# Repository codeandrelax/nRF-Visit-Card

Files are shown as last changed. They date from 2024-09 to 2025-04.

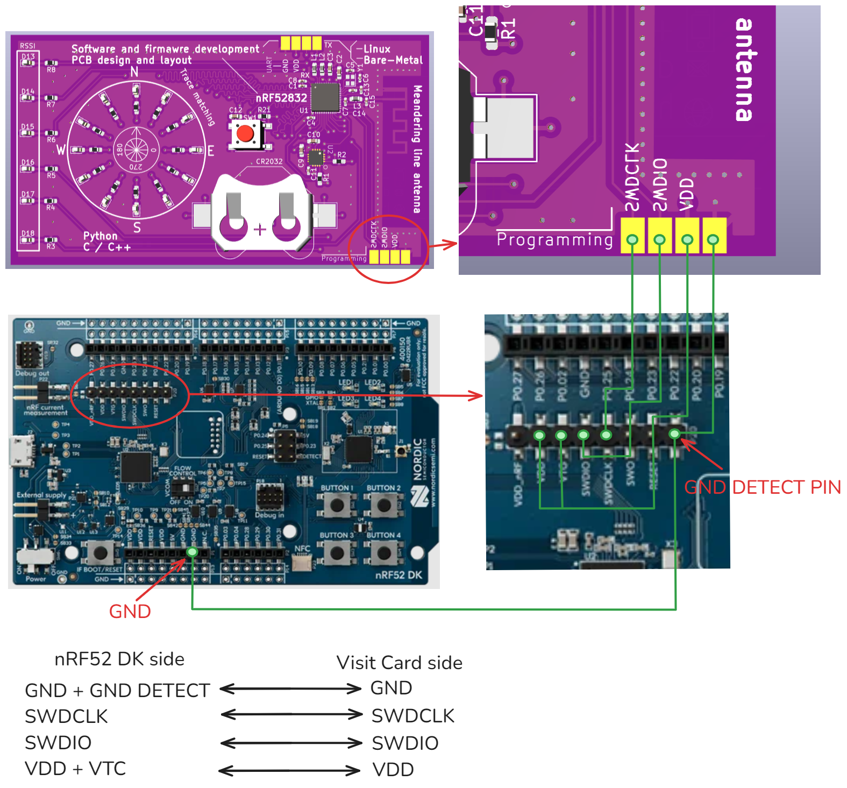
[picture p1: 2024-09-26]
visitCard_programming_witg_nRF52_DK.png

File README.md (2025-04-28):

# Bluetooth Compass Project

This project is a personal showcase of my skills in **PCB design, embedded firmware development, and Android application programming**—centered around a custom-built **Bluetooth-enabled digital compass**.

I created this project as a demonstration of my capability to design and manufacture a clean, self-contained PCB solution, free from the reliance on off-the-shelf BLE modules. It’s a manifestation of my passion for building systems from scratch, with a focus on RF design and embedded software.

---

## 🛠️ Hardware Overview

- **Microcontroller**: Nordic nRF52832 with integrated BLE support  
- **Antenna**: Custom-designed **meandering line antenna** tuned to **2.4 GHz**  
- **Magnetometer**: QMC5883L for 3-axis magnetic field sensing (I2C communication)  
- **LEDs**:  
  - 12x Blue LEDs in a circular layout to represent compass directions  
  - 6x Status LEDs: USER, CONNECTIVITY INDICATOR, HEARTBEAT  
- **Battery**: CR2032 coin cell slot  
- **Programming Interface**: SWD (SWCLK, SWDIO), UART connector  
- **Clock**: 32 MHz external crystal for BLE SoftDevice  
- **PCB Stack**: 4-layer custom design, credit-card sized  

> The reset pin is repurposed as a **user input button**. The reset functionality is disabled in software to allow this.

---

## 🔧 Firmware Overview

Firmware is built on **Zephyr RTOS**, enabling modular and modern embedded software design.

A **custom Bluetooth service**, `CompassService`, is implemented, exposing three key characteristics:

1. **Button State**  
2. **User LED Control**  
3. **Direction Output**

### 📡 Magnetometer Integration

- QMC5883L communicates over I2C.  
- Each axis (X, Y, Z) is read as a signed 16-bit value:

```c
int16_t value = (MSB << 8) | LSB;
```

- Orientation is calculated using the X and Y components:

```c
float angle_rad = atan2f((float)mag_y, (float)mag_x);
float angle_deg = angle_rad * (180.0f / M_PI);
if (angle_deg < 0) angle_deg += 360.0f;
```

The direction value is then:
- **Broadcast over BLE** using notify characteristics  
- **Rendered via LEDs** in a circular fashion to act as a real-time compass  

The system runs on the **internal RC oscillator**, while the **external crystal is reserved for BLE operations**.

---

## 📱 Android App Overview

Developed using **Android Studio**, the app uses the **Processing library** to render a dynamic compass needle.

- **BLE scanning** locates the `BluetoothCompass`  
- On connection, the app:  
  - Performs **service discovery**  
  - **Subscribes** to the `Direction` characteristic  
  - **Updates** the compass needle UI in real-time  

This part was relatively straightforward and served as a creative outlet for UI/UX.

---

## 🎯 Purpose

This project was built as a **self-test and demonstration** of:

- Designing an RF-friendly PCB with custom Bluetooth antenna  
- Working with the **nRF52 ecosystem** and BLE stack (SoftDevice + Zephyr)  
- Integrating hardware components like magnetometers and CR2032 power  
- Creating a polished **user-facing Android application**

---

## 🧠 Lessons Learned

Building this project wasn't without hiccups—but every mistake taught me something valuable:

1. **Reversed Magnetometer Pins**  
   Costly PCB error discovered only post-manufacturing. Lesson: Triple-check schematic-to-layout connections.

2. **QFN Soldering Difficulties**  
   My aging soldering iron made soldering QFN packages (magnetometer, MCU) unreliable. Eventually outsourced to **JLCPCB assembly** for these parts.

3. **Signed-to-Unsigned Mistake**  
   I accidentally cast signed 16-bit values from the magnetometer to `uint16_t`, causing direction errors—reminding me of the infamous Ariane 5 bug.

4. **Magnetometer Proximity to Battery**  
   The CR2032 placement near the magnetometer introduced magnetic interference. If I were to redo the board, I’d increase their separation.

5. **No Tilt Compensation**  
   Since the magnetometer acts as a compass only when the board is level, tilts skew the readings. A better design would include an **accelerometer** for tilt compensation:

   ```
   heading = atan2(-Y, X)
   pitch = asin(Z / sqrt(X² + Y² + Z²))
   compensated_heading = heading adjusted for pitch/roll
   ```

---

## 🏁 Conclusion

This project embodies my passion for **electronics**, **firmware engineering**, and **RF system design**. Despite having a **Master’s degree in electronics** and professional experience in embedded development, this personal build was a humbling and rewarding journey. Interestingly, the Android app—which I only work on as a hobby—turned out to be the smoothest part of the whole process!

---

## 🤝 Feedback Welcome!

I enjoy building things I can be proud of—and I’m always open to feedback and suggestions.  
If anything in this project sparks your interest or you’d like to collaborate, feel free to reach out.

## Detailed



This is how it started:



### Schematics























### Layout - bottom copper layer



### Rendered images of the board



### Soldered board



# nRF Connect notes

## How to program the board

[nRF52 DK](https://www.nordicsemi.com/Products/Development-hardware/nRF52-DK) can be used to program the visit card. 

nRF Visit Card board has exposed pads that are used for programming.
visitCard_programming_witg_nRF52_DK

### Pinout



## Internal oscilator enable

To enable internal oscilator for nRF52832 in the proj.conf file add:
````
CONFIG_CLOCK_CONTROL_NRF_K32SRC_RC=y
CONFIG_CLOCK_CONTROL_NRF_K32SRC_500PPM=y
CONFIG_CLOCK_CONTROL_NRF_K32SRC_RC_CALIBRATION=y
CONFIG_CLOCK_CONTROL_NRF_CALIBRATION_LF_ALWAYS_ON=y
````

## Enable rest pin to be input GPIO

In the overlay file add:

```
&uicr {
	/delete-property/ gpio-as-nreset;
};
```

after it make sure to call:

```
nrfjprog --eraseuicr
nrfjprog --program <path to hex file> --verify
```

 You might need to reset the board after this - unplug it and plug it back in.

## If _printk_ is not working
In the proj.conf file add:
````
CONFIG_CONSOLE=y
````
## Disabling NFC pins
Pins P0.09 and P0.10 are NFC pins and if you wan't to use them as GPIO pins you need to disable NFC.
[nrf52 enabling gpio on nfc pins](https://devzone.nordicsemi.com/f/nordic-q-a/35505/nrf52-enabling-gpio-on-nfc-pins)
```
CONFIG_NFCT_PINS_AS_GPIOS=y
```

## Enable printing via SWD IO and SWD CLK
In the proj.conf file add:
```
CONFIG_LOG=y
CONFIG_UART_CONSOLE=n
CONFIG_RTT_CONSOLE=y
CONFIG_USE_SEGGER_RTT=y
```
then you can use `printf` function.
```
uint16_t a = getAzimuth();
printf("Azimuth: %d\n", a);
```
Make sure to connect to RTT (Real-Time Transfer).



## 

 # Knowledge Library

 [nRF Connect SDK Fundamentals](https://academy.nordicsemi.com/courses/nrf-connect-sdk-fundamentals/)
 
 [Bluetooth Low Energy Fundamentals](https://academy.nordicsemi.com/courses/bluetooth-low-energy-fundamentals/)

 [Find BLE devices](https://developer.android.com/develop/connectivity/bluetooth/ble/find-ble-devices#java)

 [Processing for Android](https://android.processing.org/tutorials/android_studio/index.html)

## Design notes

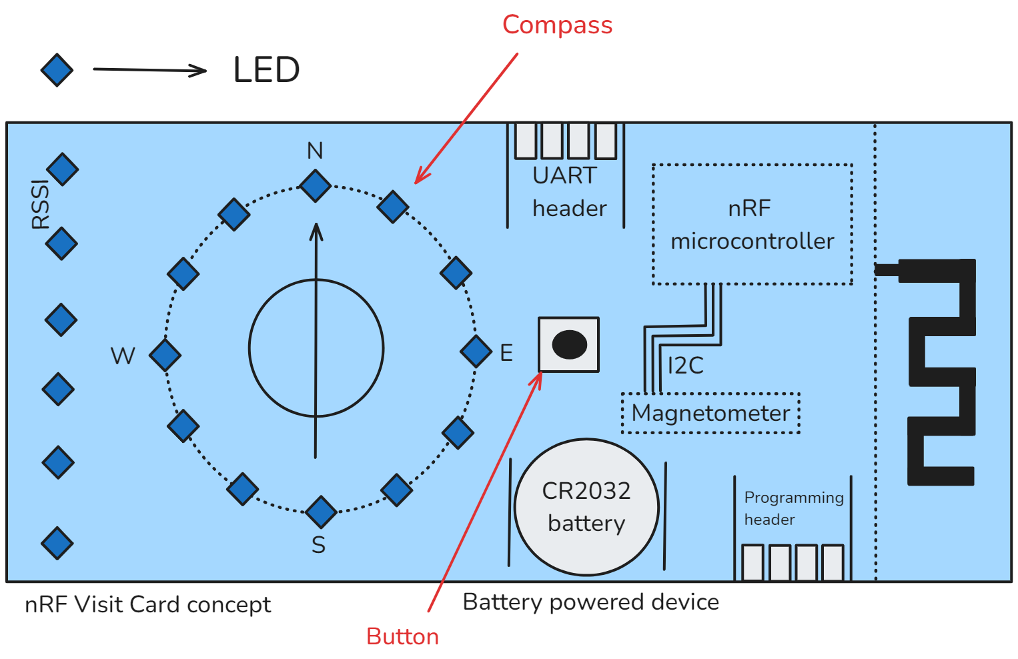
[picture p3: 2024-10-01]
nRF_visitcard_concept.png

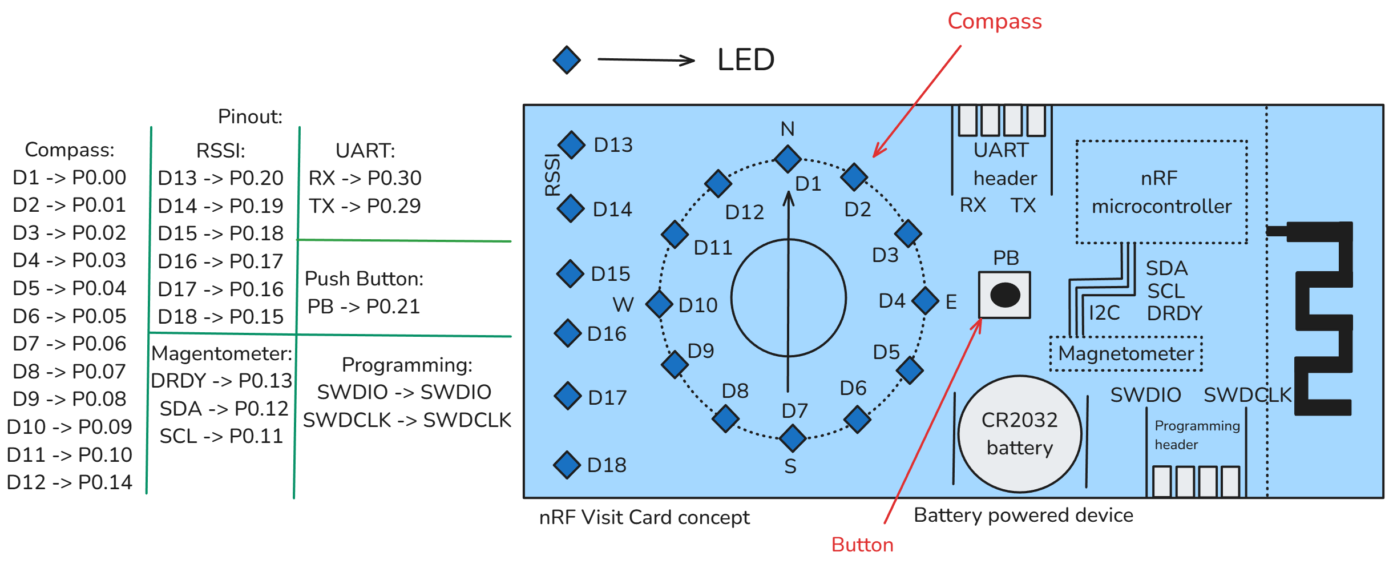
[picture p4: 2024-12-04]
nRF_visitcard_pinout.png

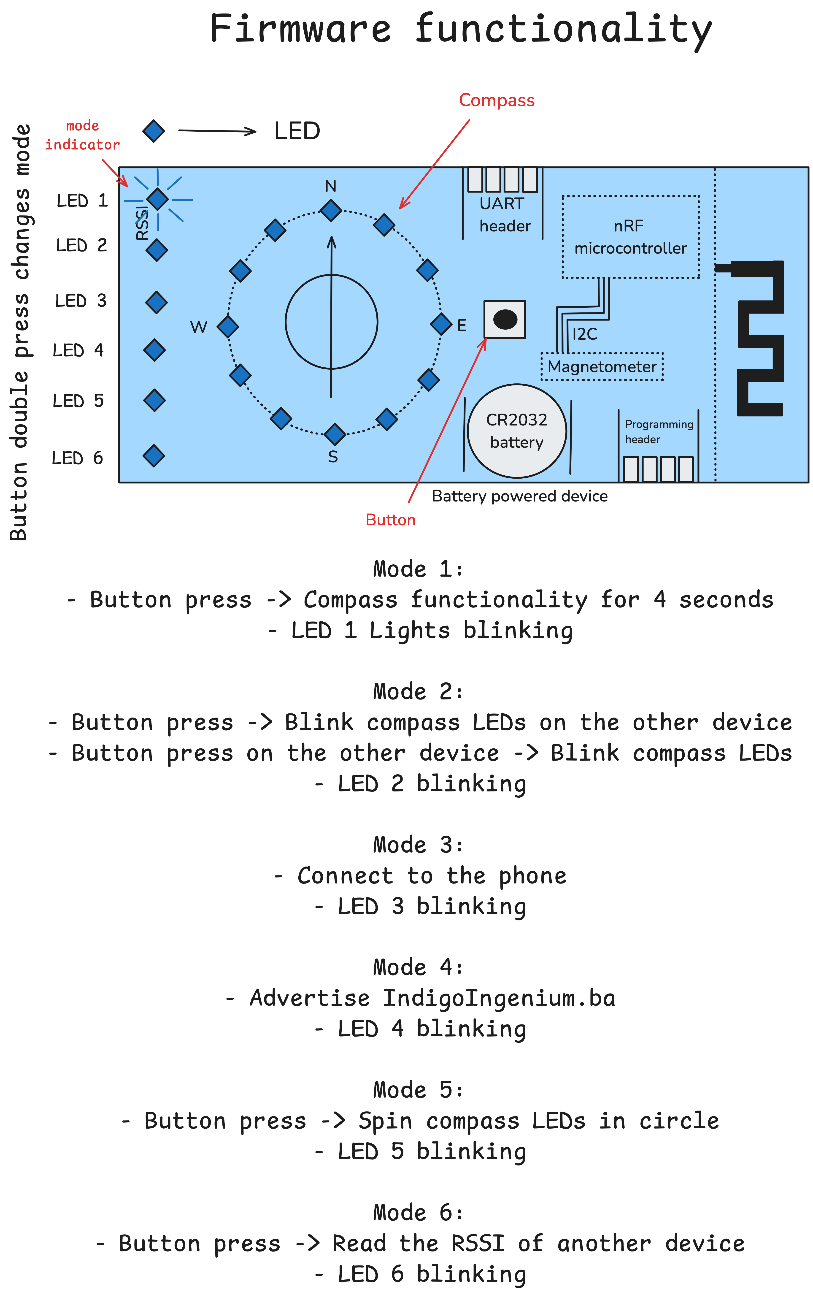
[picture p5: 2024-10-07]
nRF_visitCard_firmware_functions.png

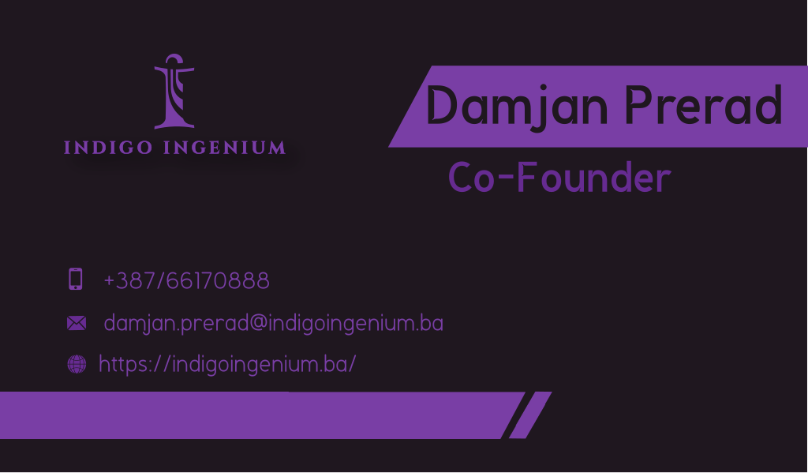
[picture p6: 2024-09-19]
nRF52832_visitcard/IndigoIngenium_visitCard.png

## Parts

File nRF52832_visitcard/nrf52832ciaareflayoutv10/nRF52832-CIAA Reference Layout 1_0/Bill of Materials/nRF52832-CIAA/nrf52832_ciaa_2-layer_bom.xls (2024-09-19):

Bill of material
Board: | nRF52832-CIAA Reference Layout (2-Layers)
Version: | 1.0
Designator | Value | Description | Footprint Doc
C1, C2, C10, C11 | 12pF | Capacitor, NP0, ±2% | 0201
C3 | 1.0pF | Capacitor, NP0, ±5% | 0201
C4, C5 | 100nF | Capacitor, X7R, ±10% | 0201
C6, C7 | 100pF | Capacitor, NP0, ±5% | 0201
C8 | 4.7µF | Capacitor, X5R, ±10% | 0603
C9 | 1.0µF | Capacitor, X5R, ±5% | 0402
L1 | 3.3nH | High frequency chip inductor ±5% | 0201
U1 | nRF52832-CIAA | Multi-protocol Bluetooth Low Energy, ANT and 2.4GHz proprietary system-on-chip | WLCSP_C50
X1 | 32MHz | XTAL SMD 2016, 32MHz, Cl=8pF, Total Tol: ±40ppm | XTAL_2016
X2 | 32.768kHz | XTAL SMD 2012, 32.768kHz, Cl=9pF, Total Tol: ±50ppm | XTAL_2012

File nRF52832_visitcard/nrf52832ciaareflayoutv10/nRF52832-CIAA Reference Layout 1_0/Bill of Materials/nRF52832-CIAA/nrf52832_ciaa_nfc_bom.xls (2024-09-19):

Bill of material
Board: | nRF52832-CIAA Reference Layout (NFC)
Version: | 1.0
Designator | Value | Description | Footprint Doc
C1, C2, C10, C11 | 12pF | Capacitor, NP0, ±2% | 0201
C3 | 1.0pF | Capacitor, NP0, ±5% | 0201
C4, C5 | 100nF | Capacitor, X7R, ±10% | 0201
C6, C7 | 100pF | Capacitor, NP0, ±5% | 0201
C8 | 4.7µF | Capacitor, X5R, ±10% | 0603
C9 | 1.0µF | Capacitor, X5R, ±5% | 0402
Ctune1, Ctune2 | TBD | Capacitor, NP0, ±5% | 0201
L1 | 3.3nH | High frequency chip inductor ±5% | 0201
L2 | 10µH | Chip inductor, IDC,min = 50 mA, ±20% | 0603
L3 | 15nH | High frequency chip inductor ±10% | 0402
U1 | nRF52832-CIAA | Multi-protocol Bluetooth Low Energy, ANT and 2.4GHz proprietary system-on-chip | WLCSP_C50
X1 | 32MHz | XTAL SMD 2016, 32MHz, Cl=8pF, Total Tol: ±40ppm | XTAL_2016
X2 | 32.768kHz | XTAL SMD 2012, 32.768kHz, Cl=9pF, Total Tol: ±50ppm | XTAL_2012

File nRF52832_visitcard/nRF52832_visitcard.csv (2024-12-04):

Comment | Designator | Footprint | LCSC
Battery_Cell | BT1 | Battery:BatteryHolder_Multicomp_BC-2001_1x2032 | C70373
100n | C1,C4,C8 | Capacitor_SMD:C_0402_1005Metric_Pad0.74x0.62mm_HandSolder | C1525
100n | C11,C16 | Capacitor_SMD:C_0805_2012Metric_Pad1.18x1.45mm_HandSolder | C1711
10u | C12 | Capacitor_SMD:C_0603_1608Metric_Pad1.08x0.95mm_HandSolder | C1691
100p | C13,C14 | Capacitor_SMD:C_0402_1005Metric_Pad0.74x0.62mm_HandSolder | C1546
4u7 | C2,C10 | Capacitor_SMD:C_0603_1608Metric_Pad1.08x0.95mm_HandSolder | C23687
1u | C3 | Capacitor_SMD:C_0603_1608Metric_Pad1.08x0.95mm_HandSolder | C15684
12p | C5,C6 | Capacitor_SMD:C_0402_1005Metric_Pad0.74x0.62mm_HandSolder | C26406
8p | C7,C15 | Capacitor_SMD:C_0402_1005Metric_Pad0.74x0.62mm_HandSolder | C126516
u22 | C9 | Capacitor_SMD:C_0603_1608Metric_Pad1.08x0.95mm_HandSolder | C1606
LED | D1,D2,D3,D4,D5,D6,D7,D8,D9,D10,D11,D12,D13,D14,D15,D16,D17,D18 | LED_SMD:LED_0603_1608Metric_Pad1.05x0.95mm_HandSolder | C5197644
10u | L1 | Inductor_SMD:L_0603_1608Metric_Pad1.05x0.95mm_HandSolder | C51942
15n | L2 | Inductor_SMD:L_0603_1608Metric_Pad1.05x0.95mm_HandSolder | C23651
3n9 | L3 | Inductor_SMD:L_0603_1608Metric_Pad1.05x0.95mm_HandSolder | C90202
2k2 | R1,R2 | Resistor_SMD:R_0603_1608Metric_Pad0.98x0.95mm_HandSolder | C25992
10k | R21 | Resistor_SMD:R_0603_1608Metric_Pad0.98x0.95mm_HandSolder | C15401
1k | R3,R4,R5,R6,R7,R8,R9,R10,R11,R12,R13,R14,R15,R16,R17,R18,R19,R20 | Resistor_SMD:R_0603_1608Metric_Pad0.98x0.95mm_HandSolder | C14676
SW_Push | SW1 | Button_Switch_SMD:SW_Push_1P1T_NO_6x6mm_H9.5mm | C499301
~ | U1 | Package_DFN_QFN:QFN-48-1EP_6x6mm_P0.4mm_EP4.6x4.6mm | C77540
~ | U2 | Package_LGA:LGA-16_3x3mm_P0.5mm | C976032
32 MHz | Y1 | Crystal:Crystal_SMD_2016-4Pin_2.0x1.6mm | C5830663

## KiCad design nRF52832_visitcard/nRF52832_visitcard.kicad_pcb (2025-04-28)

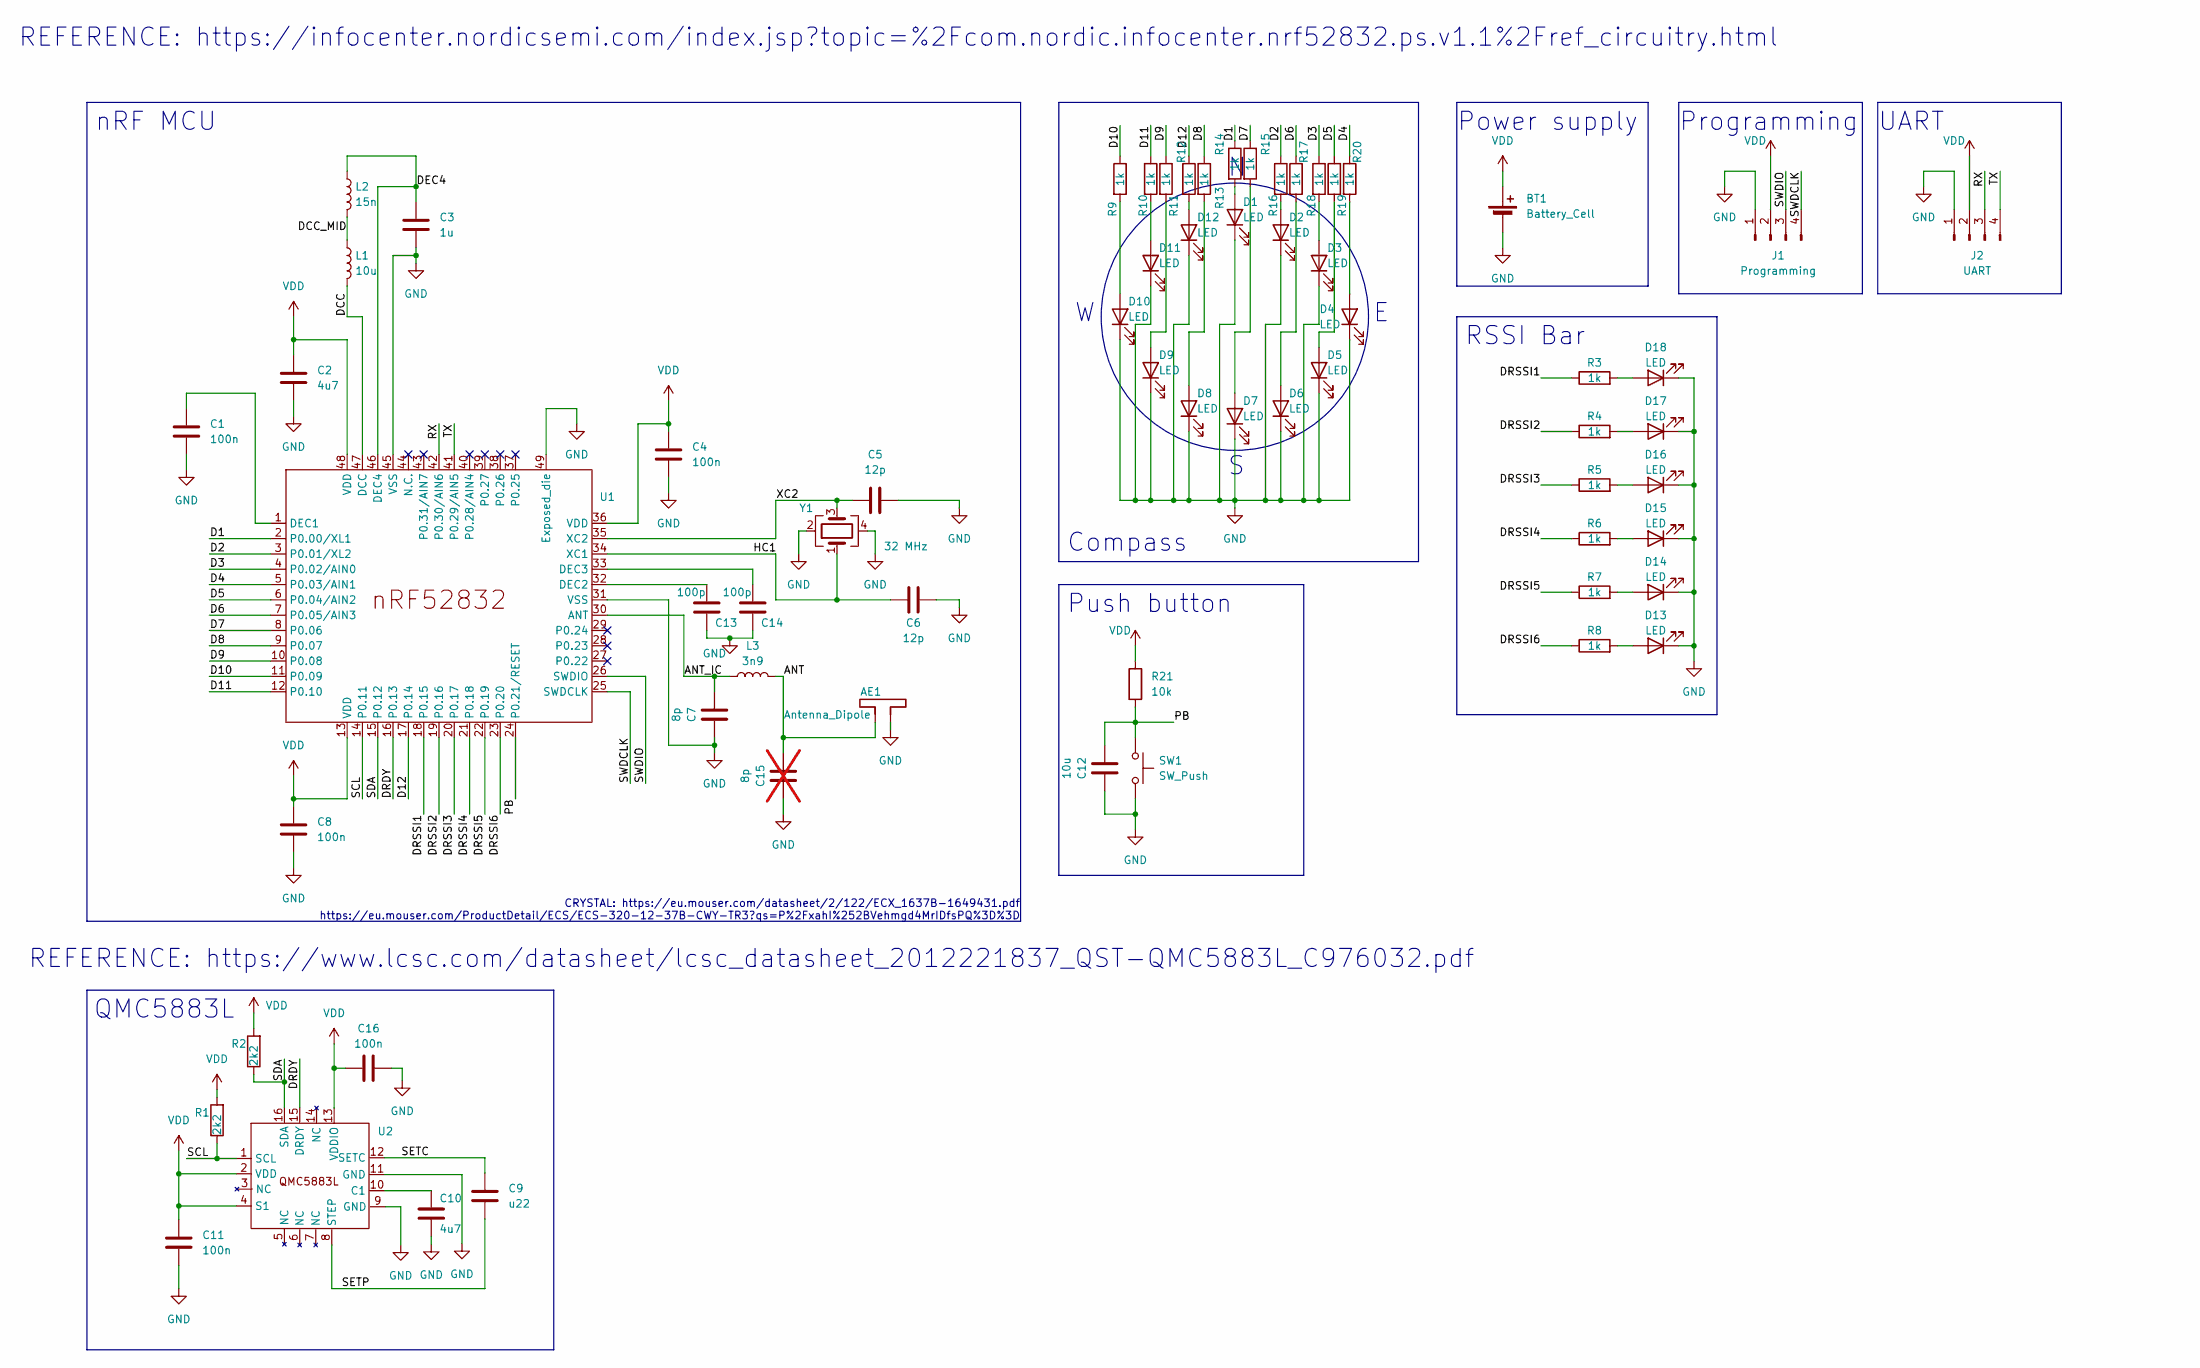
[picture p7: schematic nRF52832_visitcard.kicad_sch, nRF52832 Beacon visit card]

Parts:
AE1: Antenna_Dipole; Texas_SWRA117D_2.4GHz_Right
BT1: Battery_Cell; BatteryHolder_Multicomp_BC-2001_1x2032; LCSC C70373
C1, C4, C8: 100n; C_0402_1005Metric_Pad0.74x0.62mm_HandSolder; LCSC C1525
C2: 4u7; C_0603_1608Metric_Pad1.08x0.95mm_HandSolder; LCSC C23687
C3: 1u; C_0603_1608Metric_Pad1.08x0.95mm_HandSolder; LCSC C15684
C5, C6: 12p; C_0402_1005Metric_Pad0.74x0.62mm_HandSolder; LCSC C26406
C7: 8p; C_0402_1005Metric_Pad0.74x0.62mm_HandSolder; LCSC C126516
C9: u22; C_0603_1608Metric_Pad1.08x0.95mm_HandSolder; LCSC C1606
C10: 4u7; C_0603_1608Metric_Pad1.08x0.95mm_HandSolder; LCSC C1705
C11, C16: 100n; C_0805_2012Metric_Pad1.18x1.45mm_HandSolder; LCSC C1711
C12: 10u; C_0603_1608Metric_Pad1.08x0.95mm_HandSolder; LCSC C1691
C13, C14: 100p; C_0402_1005Metric_Pad0.74x0.62mm_HandSolder; LCSC C1546
C15: 8p; C_0402_1005Metric_Pad0.74x0.62mm_HandSolder; not fitted
D1, D2, D3, D4, D5, D6, D7, D8, D9, D10, D11, D12, D13, D14, D15, D16, D17, D18: LED; LED_0603_1608Metric_Pad1.05x0.95mm_HandSolder; LCSC C5197644
J1: Programming; SMD_edgeConnector_4pin
J2: UART; SMD_edgeConnector_4pin
L1: 10u; L_0603_1608Metric_Pad1.05x0.95mm_HandSolder; LCSC C51942
L2: 15n; L_0603_1608Metric_Pad1.05x0.95mm_HandSolder; LCSC C23651
L3: 3n9; L_0603_1608Metric_Pad1.05x0.95mm_HandSolder; LCSC C90202
R1, R2: 2k2; R_0603_1608Metric_Pad0.98x0.95mm_HandSolder; LCSC C25992
R3, R4, R5, R6, R7, R8, R9, R10, R11, R12, R13, R14, R15, R16, R17, R18, R19, R20: 1k; R_0603_1608Metric_Pad0.98x0.95mm_HandSolder; LCSC C14676
R21: 10k; R_0603_1608Metric_Pad0.98x0.95mm_HandSolder; LCSC C15401
SW1: SW_Push; SW_Push_1P1T_NO_6x6mm_H9.5mm; LCSC C499301
U1: QFN-48-1EP_6x6mm_P0.4mm_EP4.6x4.6mm; LCSC C77540
U2: LGA-16_3x3mm_P0.5mm; LCSC C976032
Y1: 32 MHz; Crystal_SMD_2016-4Pin_2.0x1.6mm; LCSC C5830663

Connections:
/ANT: AE1.1, C15.1, L3.2
/ANT_IC: C7.1, L3.1, U1.30 (ANT)
/D1: R14.1, U1.2 (P0.00/XL1)
/D2: R16.1, U1.3 (P0.01/XL2)
/D3: R18.1, U1.4 (P0.02/AIN0)
/D4: R20.1, U1.5 (P0.03/AIN1)
/D5: R19.1, U1.6 (P0.04/AIN2)
/D6: R17.1, U1.7 (P0.05/AIN3)
/D7: R15.1, U1.8 (P0.06)
/D8: R13.1, U1.9 (P0.07)
/D9: R11.1, U1.10 (P0.08)
/D10: R9.1, U1.11 (P0.09)
/D11: R10.1, U1.12 (P0.10)
/D12: R12.1, U1.17 (P0.14)
/DCC: L1.2, U1.47 (DCC)
/DCC_MID: L1.1, L2.2
/DEC4: C3.1, L2.1, U1.46 (DEC4)
/DRDY: U1.16 (P0.13), U2.15 (DRDY)
/DRSSI1: R3.1, U1.18 (P0.15)
/DRSSI2: R4.1, U1.19 (P0.16)
/DRSSI3: R5.1, U1.20 (P0.17)
/DRSSI4: R6.1, U1.21 (P0.18)
/DRSSI5: R7.1, U1.22 (P0.19)
/DRSSI6: R8.1, U1.23 (P0.20)
/HC1: C6.1, U1.34 (XC1), Y1.1
/PB: C12.1, R21.2, SW1.1, U1.24 (P0.21/RESET)
/RX: J2.3, U1.42 (P0.30/AIN6)
/SCL: R1.1, U1.14 (P0.11), U2.1 (SCL)
/SDA: R2.1, U1.15 (P0.12), U2.16 (SDA)
/SETC: C9.1, U2.12 (SETC)
/SETP: C9.2, U2.8 (STEP)
/SWDCLK: J1.4, U1.25 (SWDCLK)
/SWDIO: J1.3, U1.26 (SWDIO)
/TX: J2.4, U1.41 (P0.29/AIN5)
/XC2: C5.1, U1.35 (XC2), Y1.3
GND: AE1.2, BT1.2 (-), C1.2, C2.2, C3.2, C4.2, C5.2, C6.2, C7.2, C8.2, C10.2, C11.2, C12.2, C13.1, C14.1, C15.2, C16.2, D1.1 (K), D2.1 (K), D3.1 (K), D4.1 (K), D5.1 (K), D6.1 (K), D7.1 (K), D8.1 (K), D9.1 (K), D10.1 (K), D11.1 (K), D12.1 (K), D13.1 (K), D14.1 (K), D15.1 (K), D16.1 (K), D17.1 (K), D18.1 (K), J1.1, J2.1, SW1.2, U1.31 (VSS), U1.45 (VSS), U1.49 (Exposed_die), U2.9 (GND), U2.11 (GND), Y1.2, Y1.4
unnamed: D1.2 (A), R14.2
unnamed: D2.2 (A), R16.2
unnamed: D3.2 (A), R18.2
unnamed: D4.2 (A), R20.2
unnamed: D5.2 (A), R19.2
unnamed: D6.2 (A), R17.2
unnamed: D7.2 (A), R15.2
unnamed: D8.2 (A), R13.2
unnamed: D9.2 (A), R11.2
unnamed: D10.2 (A), R9.2
unnamed: D11.2 (A), R10.2
unnamed: D12.2 (A), R12.2
unnamed: D13.2 (A), R8.2
unnamed: D14.2 (A), R7.2
unnamed: D15.2 (A), R6.2
unnamed: D16.2 (A), R5.2
unnamed: D17.2 (A), R4.2
unnamed: D18.2 (A), R3.2
unnamed: C1.1, U1.1 (DEC1)
unnamed: C13.2, U1.32 (DEC2)
unnamed: C14.2, U1.33 (DEC3)
unnamed: C10.1, U2.10 (C1)
VDD: BT1.1 (+), C2.1, C4.1, C8.1, C11.1, C16.1, J1.2, J2.2, R1.2, R2.2, R21.1, U1.13 (VDD), U1.36 (VDD), U1.48 (VDD), U2.2 (VDD), U2.4 (S1), U2.13 (VDDIO)

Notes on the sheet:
Programming
Push button
Power supply
UART
Compass
QMC5883L
RSSI Bar
nRF MCU
REFERENCE: https://www.lcsc.com/datasheet/lcsc_datasheet_2012221837_QST-QMC5883L_C976032.pdf
CRYSTAL: https://eu.mouser.com/datasheet/2/122/ECX_1637B-1649431.pdf https://eu.mouser.com/ProductDetail/ECS/ECS-320-12-37B-CWY-TR3?qs=P%2FxahI%252BVehmgd4MrIDfsPQ%3D%3D
REFERENCE: https://infocenter.nordicsemi.com/index.jsp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

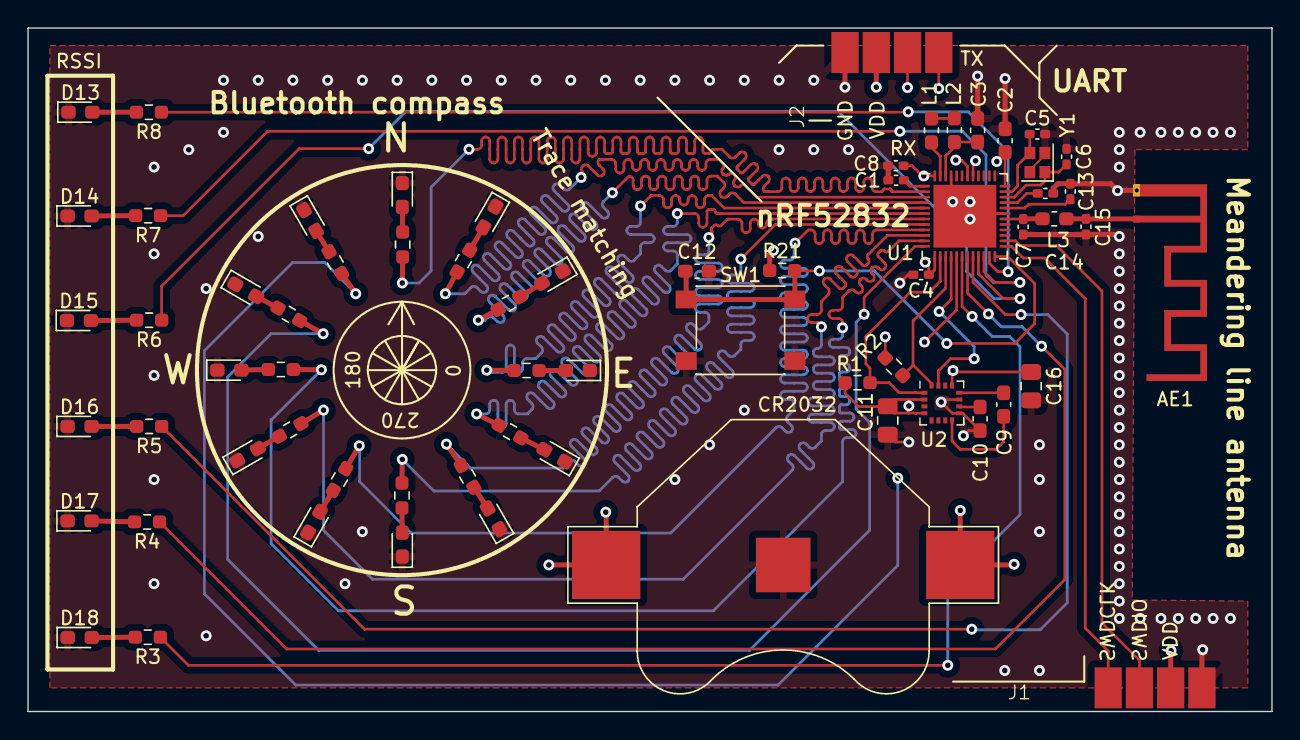
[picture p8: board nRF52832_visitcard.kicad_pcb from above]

Board: 4 copper layers, 91.0 x 50.0 mm, 67 parts (1 on the bottom side), 59 nets.

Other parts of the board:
 : Gauge_50mm_Type1_SilkScreenTop

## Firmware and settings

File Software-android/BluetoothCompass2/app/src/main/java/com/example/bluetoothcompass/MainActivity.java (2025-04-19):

package com.example.bluetoothcompass;

import android.bluetooth.BluetoothAdapter;
import android.bluetooth.BluetoothDevice;
import android.bluetooth.BluetoothGatt;
import android.bluetooth.BluetoothGattCallback;
import android.bluetooth.BluetoothGattCharacteristic;
import android.bluetooth.BluetoothGattDescriptor;
import android.bluetooth.BluetoothGattService;
import android.bluetooth.BluetoothManager;
import android.bluetooth.BluetoothProfile;
import android.bluetooth.le.BluetoothLeScanner;
import android.bluetooth.le.ScanCallback;
import android.bluetooth.le.ScanResult;
import android.content.pm.PackageManager;
import android.os.Bundle;

import androidx.activity.EdgeToEdge;
import androidx.annotation.NonNull;
import androidx.annotation.RequiresApi;
import androidx.appcompat.app.AppCompatActivity;
import androidx.core.app.ActivityCompat;
import androidx.core.graphics.Insets;
import androidx.core.view.ViewCompat;
import androidx.core.view.WindowInsetsCompat;

import androidx.appcompat.app.AppCompatActivity;
import android.content.Intent;
import android.os.Bundle;
import android.os.Handler;
import android.view.ViewGroup;
import android.widget.FrameLayout;
import processing.android.PFragment;
import processing.android.CompatUtils;
import processing.core.PApplet;

import android.os.Build;
import android.Manifest;

import java.util.ArrayList;
import java.util.UUID;

public class MainActivity extends AppCompatActivity {

    private BluetoothAdapter bluetoothAdapter;
    private BluetoothLeScanner bluetoothLeScanner;
    private BluetoothGatt bluetoothGatt;
    private Handler handler = new Handler();
    private boolean scanning = false;
    private static final long SCAN_PERIOD = 10000;
    private Sketch sketch;


    @Override
    protected void onCreate(Bundle savedInstanceState) {
        super.onCreate(savedInstanceState);
        FrameLayout frame = new FrameLayout(this);
        frame.setId(CompatUtils.getUniqueViewId());
        setContentView(frame, new ViewGroup.LayoutParams(ViewGroup.LayoutParams.MATCH_PARENT,
                ViewGroup.LayoutParams.MATCH_PARENT));

        sketch = new Sketch();
        PFragment fragment = new PFragment(sketch);
        fragment.setView(frame, this);

        if (Build.VERSION.SDK_INT >= Build.VERSION_CODES.S) {
            if (ActivityCompat.checkSelfPermission(this, Manifest.permission.BLUETOOTH_SCAN) != PackageManager.PERMISSION_GRANTED ||
                    ActivityCompat.checkSelfPermission(this, Manifest.permission.BLUETOOTH_CONNECT) != PackageManager.PERMISSION_GRANTED) {
                ActivityCompat.requestPermissions(this,
                        new String[] {
                                Manifest.permission.BLUETOOTH_SCAN,
                                Manifest.permission.BLUETOOTH_CONNECT
                        }, 1);
                return; // Wait for user to grant permission before continuing
            }
        }

        // BLE setup
        BluetoothManager bluetoothManager = (BluetoothManager) getSystemService(BLUETOOTH_SERVICE);
        bluetoothAdapter = bluetoothManager.getAdapter();

        if (bluetoothAdapter != null && bluetoothAdapter.isEnabled()) {
            bluetoothLeScanner = bluetoothAdapter.getBluetoothLeScanner();
            startScan(); // Start scanning on launch if Bluetooth is available and enabled
        } else {
            System.out.println("Bluetooth not available or not enabled");
            // You may want to prompt the user to enable Bluetooth if not enabled
            Intent enableBtIntent = new Intent(BluetoothAdapter.ACTION_REQUEST_ENABLE);
            startActivityForResult(enableBtIntent, 1); // Ask the user to enable Bluetooth
        }
    }

    @RequiresApi(api = Build.VERSION_CODES.S)
    private void startScan() {
        if (ActivityCompat.checkSelfPermission(this, Manifest.permission.BLUETOOTH_SCAN) != PackageManager.PERMISSION_GRANTED ||
                ActivityCompat.checkSelfPermission(this, Manifest.permission.BLUETOOTH_CONNECT) != PackageManager.PERMISSION_GRANTED) {

            // Request the necessary permissions if not granted
            ActivityCompat.requestPermissions(this,
                    new String[]{Manifest.permission.BLUETOOTH_SCAN, Manifest.permission.BLUETOOTH_CONNECT},
                    1);
            return; // Return early until the user grants permissions
        }

        if (bluetoothLeScanner == null) {
            System.out.println("BluetoothLeScanner is null.");
            return;
        }

        if (!scanning && bluetoothLeScanner != null) {
            handler.postDelayed(() -> {
                scanning = false;
                bluetoothLeScanner.stopScan(leScanCallback);
                System.out.println("Stopped scanning.");
            }, SCAN_PERIOD);

            scanning = true;
            try {
                bluetoothLeScanner.startScan(leScanCallback);
            } catch (SecurityException e) {
                e.printStackTrace();
                System.out.println("Missing BLE permissions.");
            }
            System.out.println("Started BLE scan...");
        }
    }

    private BluetoothGattCharacteristic ledCharacteristic;

    private final BluetoothGattCallback gattCallback = new BluetoothGattCallback() {
        @Override
        public void onConnectionStateChange(BluetoothGatt gatt, int status, int newState) {
            if (newState == BluetoothProfile.STATE_CONNECTED) {
                System.out.println("Connected to device, starting service discovery...");
                gatt.discoverServices(); // Discover services once connected
            } else if (newState == BluetoothProfile.STATE_DISCONNECTED) {
                System.out.println("Disconnected from device");
            }
        }

        @Override
        public void onServicesDiscovered(BluetoothGatt gatt, int status) {
            if (status == BluetoothGatt.GATT_SUCCESS) {
                BluetoothGattService service = gatt.getService(UUID.fromString("00001523-1212-efde-1523-785feabcd123"));
                if (service != null) {
                    BluetoothGattCharacteristic magnetometerCharacteristic = service.getCharacteristic(UUID.fromString("00001526-1212-efde-1523-785feabcd123"));
                    if (magnetometerCharacteristic != null) {
                        gatt.setCharacteristicNotification(magnetometerCharacteristic, true); // Enable notifications for this characteristic
                        BluetoothGattDescriptor descriptor = magnetometerCharacteristic.getDescriptor(UUID.fromString("00002902-0000-1000-8000-00805f9b34fb"));
                        if (descriptor != null) {
                            descriptor.setValue(BluetoothGattDescriptor.ENABLE_NOTIFICATION_VALUE);
                            gatt.writeDescriptor(descriptor); // Write descriptor to enable notifications
                        }
                    }
//                    BluetoothGattCharacteristic writeChar = service.getCharacteristic(UUID.fromString("00001525-1212-efde-1523-785feabcd123"));
//                    if (writeChar != null) {
//                        ledCharacteristic = writeChar;
//                        sketch.setLedCharacteristic(ledCharacteristic, bluetoothGatt); // Pass it to the sketch
//                        System.out.println("Passed led charachteristics to sketch");
//                    }
                }
            } else {
                System.out.println("Service discovery failed");
            }
        }

        @Override
        public void onCharacteristicChanged(BluetoothGatt gatt, BluetoothGattCharacteristic characteristic) {
            // Handle characteristic value change (notifications)
            if (characteristic.getUuid().toString().equals("00001526-1212-efde-1523-785feabcd123")) {
                int updatedValue = characteristic.getIntValue(BluetoothGattCharacteristic.FORMAT_UINT32, 0);
                System.out.println("Updated value: " + updatedValue);
                sketch.updateDirection(updatedValue);
                // Update your int parameter based on the new value
            }
        }
    };
    private void connectToDevice(BluetoothDevice device) {
        if (Build.VERSION.SDK_INT >= Build.VERSION_CODES.M) {
            bluetoothGatt = device.connectGatt(this, false, gattCallback);
        } else {
            bluetoothGatt = device.connectGatt(this, false, gattCallback);
        }
        System.out.println("Connecting to " + device.getName() + "...");
    }

    @Override
    protected void onDestroy() {
        super.onDestroy();
        if (bluetoothGatt != null) {
            bluetoothGatt.close(); // Always close the GATT connection when done
        }
    }

    private final ScanCallback leScanCallback = new ScanCallback() {
        @RequiresApi(api = Build.VERSION_CODES.S)
        @Override
        public void onScanResult(int callbackType, ScanResult result) {
            BluetoothDevice device = result.getDevice();
            String name = device.getName();
            String address = device.getAddress();
            if (name == null) name = "Unknown";

            sketch.addDevice(device);

            System.out.println("Found BLE device: " + name + " [" + address + "]");

            if (name.equals("DamjanBLE") && address.equals("F8:9E:71:CB:86:52")) {
                // Stop scanning once the device is found
                bluetoothLeScanner.stopScan(this);
                System.out.println("Found target device, connecting...");

                // Connect to the device
                connectToDevice(device);
            }
        }

        @Override
        public void onScanFailed(int errorCode) {
            super.onScanFailed(errorCode);
            System.out.println("Scan failed with error code: " + errorCode);
        }
    };

    @Override
    public void onRequestPermissionsResult(int requestCode, @NonNull String permissions[], @NonNull int[] grantResults) {
        super.onRequestPermissionsResult(requestCode, permissions, grantResults);

        if (sketch != null) {
            sketch.onRequestPermissionsResult(
                    requestCode, permissions, grantResults);
        }

        if (requestCode == 1 && grantResults.length > 0 &&
                grantResults[0] == PackageManager.PERMISSION_GRANTED &&
                grantResults[1] == PackageManager.PERMISSION_GRANTED) {
            bluetoothLeScanner = bluetoothAdapter.getBluetoothLeScanner();
            startScan();
        } else {
            System.out.println("Permissions not granted!");
        }
    }

    @Override
    public void onNewIntent(Intent intent) {
        super.onNewIntent(intent);
        if (sketch != null) {
            sketch.onNewIntent(intent);
        }
    }
}

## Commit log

2024-09-19 PCB Visit Card first push
    [nRF52832_visitcard-B_Cu.gbr, nRF52832_visitcard-B_Mask.gbr, nRF52832_visitcard-B_Paste.gbr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]
2024-09-19 3D models to PCB added
    [nRF52832_visitcard.kicad_pcb]
2024-09-26 Magnetometer reading
2024-11-21 Generating BOM
2024-11-22 Added LCSC to all the components
    [nRF52832_visitcard.kicad_sch]
2024-11-22 LCSC added to another component
    [nRF52832_visitcard.kicad_pcb, nRF52832_visitcard.kicad_sch]
2024-11-24 Board layout fix
    [nRF52832_visitcard-B_Cu.gbr, nRF52832_visitcard-B_Mask.gbr, nRF52832_visitcard-B_Paste.gbr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]
2024-12-04 Using QMC5833L instead of HMC5883L
    [nRF52832_visitcard-B_Cu.gbr, nRF52832_visitcard-B_Mask.gbr, nRF52832_visitcard-B_Paste.gbr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]
2025-04-19 Removal of old files
    [nRF52832_visitcard-B_Cu.gbr, nRF52832_visitcard-B_Mask.gbr, nRF52832_visitcard-B_Paste.gbr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]
2025-04-28 PCB details - Rotated battery holder in 3D view - Silkscreen fix
    [nRF52832_visitcard-B_Cu.gbr, nRF52832_visitcard-B_Mask.gbr, nRF52832_visitcard-B_Paste.gbr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]
2025-04-28 Firmawre: - Added firware - Added custom device tree source for bluetooth compass
    [nRF52832_visitcard.kicad_pcb]
